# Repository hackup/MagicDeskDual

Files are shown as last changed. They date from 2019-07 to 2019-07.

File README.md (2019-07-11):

# MagicDeskCart Dual

The MagicDeskCart Dual is a bank switching cartridge for the C64/C128. In reminiscence of the "Double-Ender" cartridges that were produced for the Atari 2600, the MagicDeskCart Dual allows two different sets of banks to be selected by turning the cartridge around.

There is also no warranty whatsoever. **USE AT YOUR OWN RISK!**.

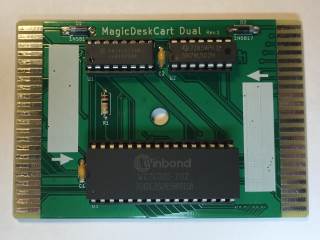
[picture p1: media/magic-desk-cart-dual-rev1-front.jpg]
MagicDeskCart Dual Rev.1 Front

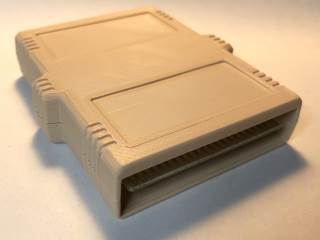
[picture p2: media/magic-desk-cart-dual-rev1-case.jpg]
MagicDeskCart Dual Rev.1 Case


See my [blog post](https://www.hackup.net/2019/07/bank-switching-cartridges/) for more details.

## License


This work is licensed under a
[Creative Commons Attribution-NonCommercial-ShareAlike 4.0 International License](http://creativecommons.org/licenses/by-nc-sa/4.0/).

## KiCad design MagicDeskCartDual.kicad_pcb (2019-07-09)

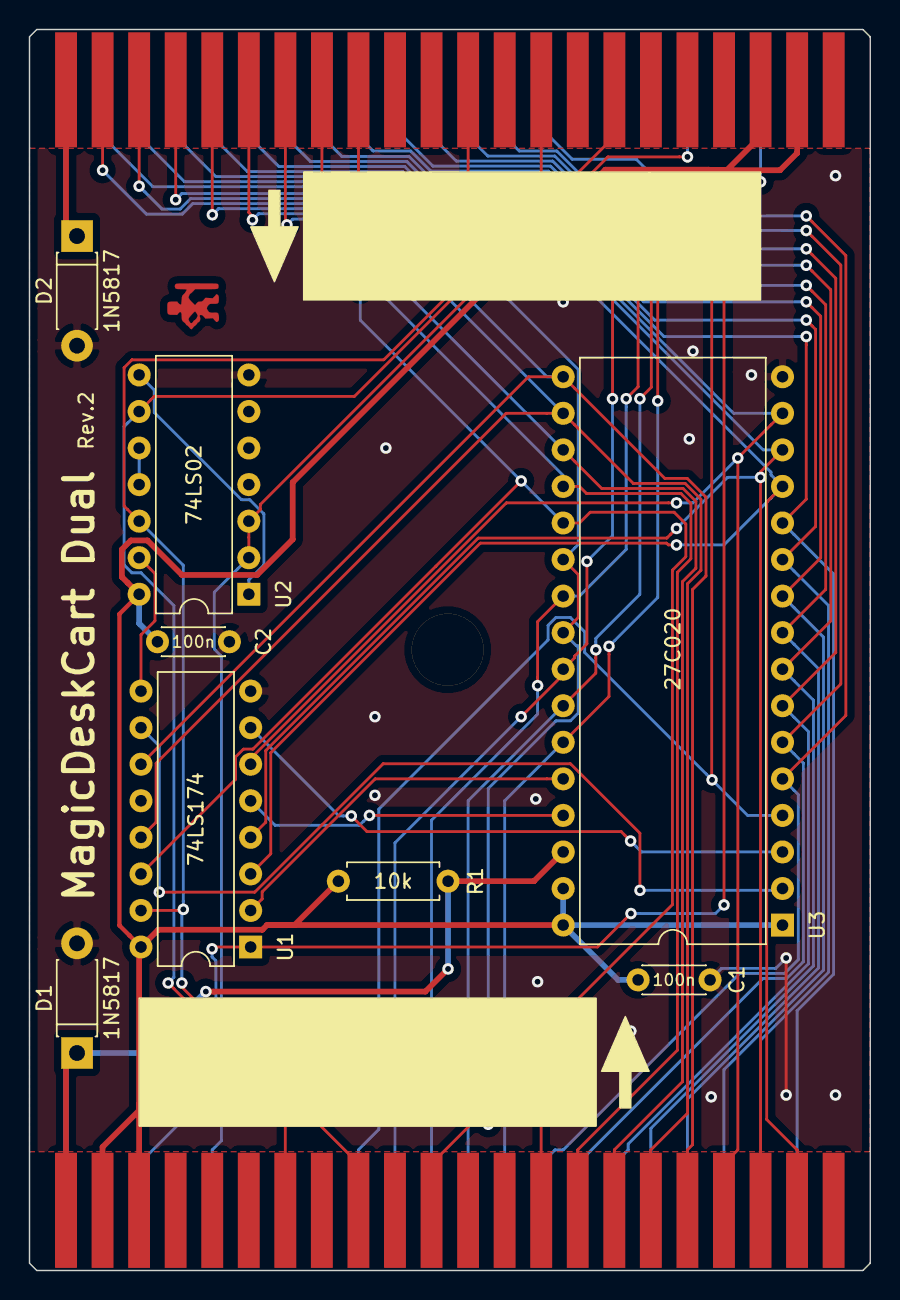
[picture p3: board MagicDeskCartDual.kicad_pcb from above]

Board: 2 copper layers, 58.4 x 86.2 mm, 10 parts (0 on the bottom side), 37 nets.

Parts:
C1, C2: 100n; C_Disc_D4.3mm_W1.9mm_P5.00mm
D1, D2: 1N5817; D_DO-41_SOD81_P7.62mm_Horizontal
R1: 10k; R_Axial_DIN0207_L6.3mm_D2.5mm_P7.62mm_Horizontal
U1: 74LS174; DIP-16_W7.62mm
U2: 74LS02; DIP-14_W7.62mm
U3: 27C020; DIP-32_W15.24mm
U4, U5: C64-Exp-Port; C64-Cart-NoSilkS

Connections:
+5V: C1.1, C2.1, R1.1, U1.16, U2.14, U3.1, U3.31, U3.32, U4.2, U4.3, U5.2, U5.3
/A0: U3.12, U4.Y, U5.Y
/A1: U3.11, U4.X, U5.X
/A2: U3.10, U4.W, U5.W
/A3: U3.9, U4.V, U5.V
/A4: U3.8, U4.U, U5.U
/A5: U3.7, U4.T, U5.T
/A6: U3.6, U4.S, U5.S
/A7: U3.5, U4.R, U5.R
/A8: U3.27, U4.P, U5.P
/A9: U3.26, U4.N, U5.N
/A10: U3.23, U4.M, U5.M
/A11: U3.25, U4.L, U5.L
/A12: U3.4, U4.K, U5.K
/D0: U1.3, U3.13, U4.21, U5.21
/D1: U1.4, U3.14, U4.20, U5.20
/D2: U1.6, U3.15, U4.19, U5.19
/D3: U1.11, U3.17, U4.18, U5.18
/D4: U1.13, U3.18, U4.17, U5.17
/D5: U3.19, U4.16, U5.16
/D6: U3.20, U4.15, U5.15
/D7: U1.14, U3.21, U4.14, U5.14
/EN: U1.9, U2.13
/S13: U1.2, U3.28
/S14: U1.5, U3.29
/S15: U1.7, U3.3
/S16: U1.10, U3.2
EXROM: U1.15, U2.12, U4.9, U5.9
GND: C1.2, C2.2, D1.2, D2.2, U1.8, U2.7, U3.16
GND0: D1.1, R1.2, U3.30, U4.1, U4.A
GND1: D2.1, U5.22, U5.Z
IO1: U2.9, U4.7, U5.7
unnamed: U2.1, U2.8
unnamed: U2.10, U2.11
PHI2: U2.2, U2.3, U4.E, U5.E
RESET: U1.1, U4.C, U5.C
ROML: U3.22, U3.24, U4.11, U5.11

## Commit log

2019-06-17 Initial import.
    [MagicDeskCartDual.kicad_pcb, MagicDeskCartDual.sch]
2019-06-17 Tuning layout.
    [MagicDeskCartDual.kicad_pcb]
2019-06-18 Prepare for rev.1
    [MagicDeskCartDual.kicad_pcb]
2019-07-08 Moved traces away from the board edge.
    [MagicDeskCartDual.kicad_pcb]
2019-07-09 Added readme.
    [MagicDeskCartDual.kicad_pcb]
